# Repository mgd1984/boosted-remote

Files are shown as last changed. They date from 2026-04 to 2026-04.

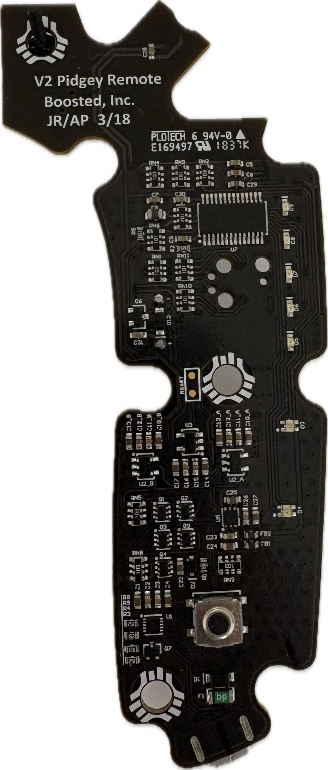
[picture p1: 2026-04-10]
mechanical/references/boosted_remote_pcb_front.png

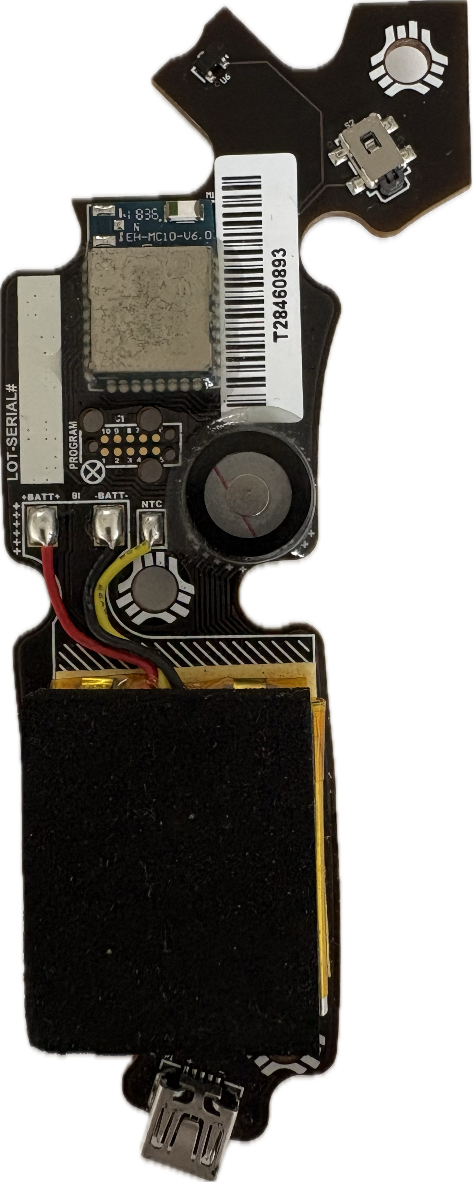
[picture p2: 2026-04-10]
mechanical/references/boosted_remote_pcb_back.png

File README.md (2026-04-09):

# Boosted Remote Reverse-Engineering Starter

This repo contains a first-pass reverse-engineered hardware recreation of the Boosted Boards thumbwheel remote:

- a Blender-generated enclosure
- a KiCad schematic
- a KiCad PCB
- documented assumptions tying the mechanical and electrical work back to source material

This is not a firmware-complete clone. The hardware is designed to match the known control architecture and packaging constraints while using currently accessible parts and a reproducible scripted workflow.

## Source Anchors

- Boosted USA product page for the later thumbwheel remote exterior reference:
  - <https://boostedusa.com/products/boosted-remote>
- Beam Break BLE reverse-engineering notes confirming later remote BLE behavior and pairing model:
  - <https://beambreak.org/articles/remote_ble_ids/>
- XR General Hospital replacement PCBA product confirming that a retrofit board in the original enclosure is practical:
  - <https://www.xrgeneralhospital.com/beta/p/remote-controller-pcba>

## Generated Assets

- Active enclosure blend: `outputs/blender/boosted_remote_enclosure.blend`
- Active PCB review blend: `outputs/blender/boosted_remote_pcb_all_layers.blend`
- Build123d CAD package: `mechanical/cad/`
- Build123d generator CLI: `mechanical/scripts/build_enclosure.py`
- Proxy-section extractor: `mechanical/scripts/analyze_proxy_glb.py`
- KiCad project: `electrical/kicad/boosted_remote.kicad_pro`
- Live board and schematic: `electrical/kicad/boosted_remote.kicad_pcb`, `electrical/kicad/boosted_remote.kicad_sch`
- Routing packet script: `electrical/scripts/route_packets.py`
- Netclass configurator: `electrical/scripts/configure_netclasses.py`
- Blender export path: `electrical/scripts/export_kicad_to_blender.py`
- Shared parameters: `config/remote_params.json`
- Reverse-engineering notes: `docs/reverse_engineering_notes.md`
- Build123d pipeline notes: `docs/build123d_enclosure.md`
- Repo navigation map: `docs/repo_map.md`

## Where To Work Now

- Mechanical source of truth: `mechanical/cad/`
- Generated Blender outputs: `outputs/blender/`
- Mechanical build entry point: `mechanical/scripts/build_enclosure.py`
- Shared parameter contract: `config/remote_params.json`
- Active KiCad project: `electrical/kicad/boosted_remote.kicad_pro`
- Active board and schematic: `electrical/kicad/boosted_remote.kicad_pcb`, `electrical/kicad/boosted_remote.kicad_sch`
- Electrical utilities and routing helpers: `electrical/scripts/`
- Mechanical utilities: `mechanical/scripts/`
- Historical electrical scripts: `history/electrical/scripts/`
- Historical mechanical scripts and studies: `history/mechanical/`
- Historical utilities: `history/utilities/`

## Repo Shape

- `electrical/kicad/`: live KiCad project only
- `electrical/scripts/`: active live-board utilities only
- `mechanical/cad/`: code-first enclosure source of truth
- `mechanical/scripts/`: active enclosure utilities only
- `mechanical/references/`: supporting 2D outline reference assets used by the CAD pipeline
- `outputs/`: generated Blender scenes, renders, and scratch outputs
- `history/electrical/`: older routing and migration helpers
- `history/mechanical/`: non-canonical lineage, experiments, displaced scenes, and older scripts
- `history/utilities/`: historical support scripts and geometry probes
- `config/`: shared project configuration and parameter contracts
- `docs/`: workflow notes plus `docs/repo_map.md` for a quick navigation guide

## Current Scope

- Boosted-style ergonomic shell with split enclosure
- thumbwheel opening and internal hall sensor location
- mini-USB charge-port cutout for external visual fidelity
- 1S LiPo power, charger, LDO, BLE MCU, LEDs, buzzer, deadman trigger, programming header
- first-pass PCB shaped to the enclosure cavity
- first-pass build123d enclosure generation for STEP/STL prototype outputs

## Verification Status

- Schematic ERC is down to warnings only on the generated custom-library setup.
- The promoted live PCB checkpoint is:
  - `electrical/kicad/boosted_remote.kicad_pcb`
  - 3 DRC warnings, all silkscreen-only
  - 25 unconnected items remaining
- The live board now includes validated packetized routing improvements over the original generator baseline.
  - Clean promoted packets so far: upper `SW1 -> U4` ground stitch and `PWR_BTN` escape/routing packet
- Experimental routing passes are only promoted when they reduce the open count without introducing blocker DRC categories.

## Known Gaps

- No firmware is included
- Dimensions are inferred and should be validated against a physical remote before fabrication
- The BLE protocol implementation required to pair with an original board is outside this repo
- The trigger and thumbwheel mechanism are mechanically approximated, not metrology-matched

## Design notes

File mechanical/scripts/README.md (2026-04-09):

# Mechanical Scripts

This folder keeps the active mechanical workflow entry points at the top level.

## Active Utilities

- `build_enclosure.py`
  - Main build123d enclosure generator.
- `analyze_proxy_glb.py`
  - Samples proxy cross-sections for enclosure fitting.

Older reconstruction and part-study scripts were moved to
`history/mechanical/scripts/`.

Use `mechanical/cad/` with the top-level scripts here for current enclosure
work.

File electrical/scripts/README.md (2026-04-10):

# Electrical Scripts

This folder keeps only the active live-board utilities at the top level.

Older one-off routing or migration helpers were moved to
`history/electrical/scripts/`.

## Primary Utilities

- `configure_netclasses.py`
  - Applies the project netclass layout.
- `export_jlc_bom.py`
  - Exports a JLCPCB-formatted BOM CSV filtered to the same placed parts as the CPL.
- `export_jlc_cpl.py`
  - Exports a JLCPCB-formatted CPL/pick-and-place CSV from the live KiCad board.
- `export_kicad_to_blender.py`
  - Regenerates PCB review assets for Blender.
- `import_kicad_blender_scene.py`
  - Blender-side importer used by the export script.
- `sync_board_outline.py`
  - Syncs the board outline from a chosen source contour layer. Defaults to the
    current `User.1` workflow.
- `update_pcb_outline_target.py`
  - Rebuilds `mechanical/references/boosted_remote_pcb_outline_target.svg`
    from the cleaned front/back PCB reference PNGs, mirroring the rear image and
    only blending it where the lower body is not occluded.

## Preferred Routing Flow

- `autoroute_iterate.py`
  - Primary routing automation path. Runs the KiCad DSN -> Freerouting -> SES
    -> DRC loop against a chosen board/report pair and only promotes an
    iteration when blocker-category counts do not regress and either opens or
    blocker counts improve. Use `--sync-outline-source pcb-svg` when the pass
    must route against `mechanical/references/boosted_remote_pcb_outline_target.svg`
    rather than whatever outline is already stored in the board file.

## Board Maintenance Utilities

- `sync_esp32_antenna_keepout.py`
  - Board-specific keepout normalization for the ESP32 module footprint.
- `sync_usb_footprint.py`
  - Board-specific re-sync of the generated local USB footprint onto the live
    board.

## Deterministic Manual Routing

- `manual_route_packets.py`
  - Deterministic packetized copper edits retained for explicit experiments and
    documented escape patterns. Prefer `autoroute_iterate.py` for normal routing
    passes.
- `rework_outline_candidate_nwx.py`
  - Candidate-board hotspot prep and deterministic reroute helper. Use
    `--ripup-only` when you want to clear edge-conflicting corridors before
    handing the board to `autoroute_iterate.py`.

## Baseline Generation

- `generate_kicad_remote.py`
  - Original project generator. Useful for reconstructing the baseline, but the
    live board is now manually maintained.
- `build_usb_mini_footprint.py`
  - Creates the local USB footprint variant used by the project.

Historical routing helpers now live under `history/electrical/scripts/`.

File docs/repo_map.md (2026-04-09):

# Repo Map

This repo is easier to navigate if you treat it as three layers: live sources,
active working files, and exploratory lineage.

## Live Sources

- `electrical/kicad/boosted_remote.kicad_pcb`
  - Current live board. This is the electrical source of truth.
- `electrical/kicad/boosted_remote.kicad_sch`
  - Current live schematic.
- `electrical/kicad/boosted_remote.kicad_pro`
  - Current KiCad project file.
- `electrical/kicad/boosted_remote.pretty/`
  - Custom footprint library used by the live board.
- `mechanical/cad/`
  - Current code-first enclosure model and validation logic.
- `mechanical/references/`
  - Supporting reference outlines consumed by the mechanical CAD package.
- `config/remote_params.json`
  - Shared geometry and packaging parameter contract.

## Active Working Areas

- `outputs/blender/boosted_remote_enclosure.blend`
  - Current enclosure output scene.
- `outputs/blender/boosted_remote_pcb_all_layers.blend`
  - Current PCB visualization / fit-check output scene.
- `mechanical/scripts/build_enclosure.py`
  - Main entry point for build123d enclosure generation.
- `electrical/scripts/export_kicad_to_blender.py`
  - Refresh the PCB review blend from the live KiCad board.
- `electrical/scripts/route_packets.py`
  - Main scripted routing helper for the live board.
- `electrical/scripts/configure_netclasses.py`
  - Applies netclass structure to the live project.
- `electrical/scripts/autoroute_iterate.py`
  - Specialized DSN -> Freerouting -> SES loop for automated routing passes.
- `mechanical/scripts/analyze_proxy_glb.py`
  - Samples proxy sections for the current enclosure workflow.

## Exploratory / Reference Areas

- `history/electrical/scripts/`
  - Older electrical routing and migration helpers retained for reference.
- `history/mechanical/`
  - Non-canonical geometry studies, displaced Blender scenes, and older mechanical scripts.
- `history/utilities/`
  - Historical support scripts and geometry probes.
- `outputs/renders/`
  - Output visuals, not a source directory.
- `outputs/tmp/`
  - Disposable generated intermediate data.

## Electrical Script Tiers

### Use most often

- `electrical/scripts/route_packets.py`
- `electrical/scripts/configure_netclasses.py`
- `electrical/scripts/export_kicad_to_blender.py`
- `electrical/scripts/sync_board_outline_from_user1.py`
- `electrical/scripts/sync_esp32_antenna_keepout.py`
- `electrical/scripts/sync_usb_footprint.py`

### Specialized live-board helpers

- `electrical/scripts/autoroute_iterate.py`
  - Use this when you want the DSN -> Freerouting -> SES iteration loop instead
    of manual packet routing.

### Baseline generators / setup

- `electrical/scripts/generate_kicad_remote.py`
- `electrical/scripts/build_usb_mini_footprint.py`

### Older packet experiments and migration helpers

- `history/electrical/scripts/manual_finish_route.py`
- `history/electrical/scripts/manual_route_signals.py`
- `history/electrical/scripts/rework_negative_bottom_cluster.py`
- `history/electrical/scripts/rework_to_two_layer.py`
- `history/electrical/scripts/rewrite_negative_bottom_cluster.py`

If a task touches the live board, start in `electrical/kicad/` and only reach for
the older helpers when a doc explicitly points to them.

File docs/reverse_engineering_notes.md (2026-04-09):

# Reverse-Engineering Notes

## What the sources support

The public source material is enough to establish the broad architecture of the later Boosted remote:

- The production remote uses a thumbwheel-driven control scheme and a compact hand-held enclosure.
- The community reverse-engineering work documents BLE-based communication and pairing behavior for the later remote family.
- Third-party replacement PCBAs exist that are intended to fit the original enclosure, which strongly suggests the packaging is simple enough to reproduce with a single custom board and a split shell.

## What is inferred here

The exact original board stack, component values, and enclosure dimensions are not fully public, so this repo makes explicit engineering assumptions:

- Enclosure style: Boosted-inspired later-generation remote, not the older trigger-only remote
- Exterior size: approximately 136 mm tall, 54 mm max width, 20 mm thick
- Shell construction: front and rear printed halves with screw bosses and a single internal PCB
- Battery: 1S LiPo in the 400 mAh to 600 mAh range
- Charging: mini-USB retained for exterior fidelity
- Logic/radio: ESP32-C3 module used as a practical BLE-capable stand-in
- Throttle sensing: linear hall sensor aligned to a thumbwheel magnet
- Safety input: rear deadman switch
- Indicators: five battery LEDs plus two status LEDs

## Why the hardware is modernized

Several original parts are either unknown, inconvenient to source, or tightly coupled to proprietary firmware. The design therefore substitutes accessible parts while preserving the same functional block diagram:

- `ESP32-C3-WROOM-02` replaces the unknown original radio/MCU
- `MCP73831-2-OT` provides simple 1S charging
- `TLV75533PDBV` provides clean 3.3 V regulation from the LiPo rail
- `DRV5055A3xDBZxQ1` provides a 3.3 V linear hall sensor suitable for wheel position sensing

## Mechanical intent

The enclosure is intentionally parametric and script-generated:

- the same parameter file drives the shell proportions and PCB cavity assumptions
- the thumbwheel pocket and hall sensor location are aligned by design
- the PCB outline is narrower than the outer shell so the printed enclosure can absorb final fit tweaks

## Internal layout target

An internal reference photo now anchors the first-order packaging assumptions:

- thumbwheel mechanism occupies the upper head volume, with the hall sensor placed just below and to the right of the wheel axis
- BLE/radio module sits in the upper-left third of the main PCB
- buzzer sits near the middle of the grip section
- LiPo pouch cell occupies most of the lower half of the enclosure
- mini-USB sits on the tail centerline

The current KiCad placement and Blender reference bodies are tuned toward that arrangement rather than a generic handheld remote.

## Validation standard for this pass

This first pass is considered successful if:

- the Blender enclosure opens cleanly and shows the intended shell split and cutouts
- the KiCad schematic opens without format errors
- the KiCad PCB opens, shows the expected footprint population, and passes a first DRC pass or at least reports a bounded set of remaining issues

Anything beyond that should be treated as prototype iteration work, not historical certainty.

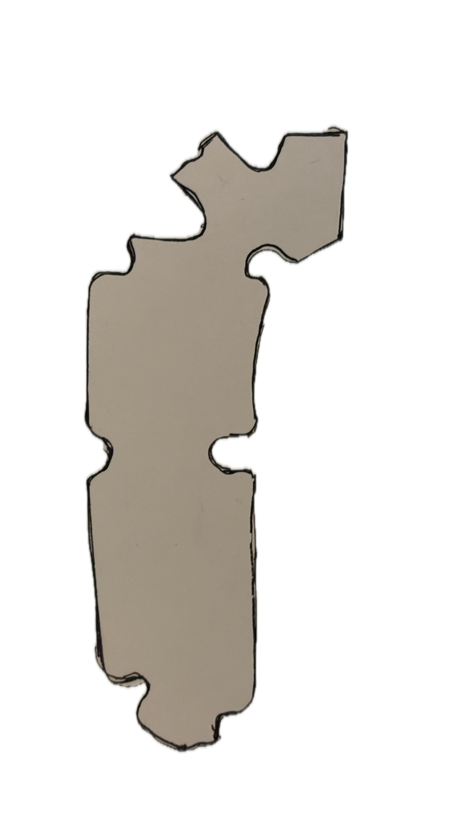
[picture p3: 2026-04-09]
mechanical/references/boosted_remote_pcb_outline_rough.png

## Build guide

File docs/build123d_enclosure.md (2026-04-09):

# Build123d Enclosure Pipeline

This repo now has a code-first mechanical path in addition to the existing Blender generator.

## Source Of Truth

- `config/remote_params.json` remains the primary parameter contract.
- `electrical/scripts/generate_kicad_remote.py` remains the fallback board-outline source when the live board does not already define `Edge.Cuts`.
- `mechanical/cad/` contains the build123d-driven enclosure model, validation, and export logic.

## What This Generates

- front shell
- rear shell
- full shell
- a simplified PCB/component envelope for visual clearance checks

## Quick Start

Install the CAD dependency:

```bash
python -m pip install -r requirements-mechanical.txt
```

Validate the current parameter set without generating solids:

```bash
python mechanical/scripts/build_enclosure.py --validate-only
```

Refresh the exterior profile stations from the proxy reconstruction GLB:

```bash
/Applications/Blender.app/Contents/MacOS/Blender --background --python mechanical/scripts/analyze_proxy_glb.py -- --repo-root "$PWD" --glb "$PWD/history/mechanical/proxy/TewTCTh6nBM-A_J6JKsw__trellis2_0d811f951772406a86d5d8f20232885d.glb" --out "$PWD/outputs/tmp/proxy_sections.json" --slice-step-mm 8.0
```

Generate the first-pass build123d enclosure outputs:

```bash
python mechanical/scripts/build_enclosure.py --formats step stl
```

Outputs are written to `outputs/build123d/` by default.

## Current Scope

This first pass is intentionally focused on:

- shell proportions and split-line
- proxy-driven exterior station fitting from the reconstructed GLB
- PCB cavity envelope
- thumbwheel, USB, LED, and button openings
- mounting bosses and counterbores
- parameter validation for early prototype iterations

It does not yet attempt a metrology-grade match to an original remote shell.

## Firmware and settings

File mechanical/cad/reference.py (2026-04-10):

from __future__ import annotations

import ast
import json
import re
import xml.etree.ElementTree as ET
from functools import lru_cache
from pathlib import Path

from .kicad_layout import load_live_board_layout
from .params import MechanicalParams


SHELL_SVG_OUTLINE_PATH = Path("mechanical/references/boosted_remote_outline_smooth_pixels.svg")
PCB_SVG_OUTLINE_PATH = Path("mechanical/references/boosted_remote_pcb_outline_target.svg")


@lru_cache(maxsize=4)
def board_outline_points(repo_root: Path) -> tuple[tuple[float, float], ...]:
    board_path = repo_root / "electrical" / "kicad" / "boosted_remote.kicad_pcb"
    board_text = board_path.read_text(encoding="utf-8")
    params_path = repo_root / "config" / "remote_params.json"
    mechanical = json.loads(params_path.read_text(encoding="utf-8"))["mechanical"]
    layout = load_live_board_layout(repo_root, mechanical)
    edge_points = _edge_cuts_outline_points(board_text, layout.offset_x_mm, layout.offset_y_mm)
    if edge_points is not None:
        return edge_points

    source_path = repo_root / "electrical" / "scripts" / "generate_kicad_remote.py"
    module = ast.parse(source_path.read_text(encoding="utf-8"), filename=str(source_path))
    for node in module.body:
        if isinstance(node, ast.FunctionDef) and node.name == "board_outline":
            for statement in node.body:
                if isinstance(statement, ast.Return):
                    points = ast.literal_eval(statement.value)
                    return tuple((float(x), float(y)) for x, y in points)
    raise RuntimeError("Unable to locate board_outline() in electrical/scripts/generate_kicad_remote.py")


def _edge_cuts_outline_points(board_text: str, offset_x_mm: float, offset_y_mm: float) -> tuple[tuple[float, float], ...] | None:
    blocks: list[str] = []
    current: list[str] = []
    depth = 0
    in_block = False
    for line in board_text.splitlines():
        stripped = line.lstrip()
        if not in_block and stripped.startswith("(gr_line"):
            in_block = True
            current = [line]
            depth = line.count("(") - line.count(")")
            if depth <= 0:
                block = "\n".join(current)
                if '(layer "Edge.Cuts")' in block:
                    blocks.append(block)
                in_block = False
            continue
        if in_block:
            current.append(line)
            depth += line.count("(") - line.count(")")
            if depth <= 0:
                block = "\n".join(current)
                if '(layer "Edge.Cuts")' in block:
                    blocks.append(block)
                in_block = False

    if not blocks:
        return None

    points: list[tuple[float, float]] = []
    for index, block in enumerate(blocks):
        start_match = re.search(r"\(start\s+([-0-9.]+)\s+([-0-9.]+)\)", block)
        end_match = re.search(r"\(end\s+([-0-9.]+)\s+([-0-9.]+)\)", block)
        if start_match is None or end_match is None:
            continue
        start = (float(start_match.group(1)) - offset_x_mm, float(start_match.group(2)) - offset_y_mm)
        end = (float(end_match.group(1)) - offset_x_mm, float(end_match.group(2)) - offset_y_mm)
        if index == 0:
            points.append(start)
        points.append(end)

    if len(points) < 4:
        return None
    if points[0] != points[-1]:
        points.append(points[0])
    return tuple(points)


@lru_cache(maxsize=8)
def user_layer_contour_points(repo_root: Path, layer_name: str = "User.1") -> tuple[tuple[float, float], ...]:
    params_path = repo_root / "config" / "remote_params.json"
    mechanical = json.loads(params_path.read_text(encoding="utf-8"))["mechanical"]
    layout = load_live_board_layout(repo_root, mechanical)
    board_path = repo_root / "electrical" / "kicad" / "boosted_remote.kicad_pcb"
    board_text = board_path.read_text(encoding="utf-8")

    block_lines: list[str] = []
    current: list[str] = []
    depth = 0
    in_block = False
    for line in board_text.splitlines():
        stripped = line.lstrip()
        if not in_block and stripped.startswith("(gr_poly"):
            in_block = True
            current = [line]
            depth = line.count("(") - line.count(")")
            if depth <= 0:
                candidate = "\n".join(current)
                if f'(layer "{layer_name}")' in candidate:
                    block_lines = current
                    break
                in_block = False
            continue

        if in_block:
            current.append(line)
            depth += line.count("(") - line.count(")")
            if depth <= 0:
                candidate = "\n".join(current)
                if f'(layer "{layer_name}")' in candidate:
                    block_lines = current
                    break
                in_block = False

    if not block_lines:
        raise RuntimeError(f"Unable to locate {layer_name} contour polygon in electrical/kicad/boosted_remote.kicad_pcb")

    points = [
        (float(x_mm) - layout.offset_x_mm, float(y_mm) - layout.offset_y_mm)
        for line in block_lines
        for x_mm, y_mm in re.findall(r"\(xy\s+([-0-9.]+)\s+([-0-9.]+)\)", line)
    ]
    if len(points) < 4:
        raise RuntimeError(f"{layer_name} contour polygon does not contain enough points")
    if points[0] != points[-1]:
        points.append(points[0])
    return tuple(points)


@lru_cache(maxsize=4)
def user1_contour_points(repo_root: Path) -> tuple[tuple[float, float], ...]:
    return user_layer_contour_points(repo_root, "User.1")


@lru_cache(maxsize=4)
def user1_shell_contour_points(repo_root: Path, pcb_shell_center_x_mm: float) -> tuple[tuple[float, float], ...]:
    return tuple((x_mm - pcb_shell_center_x_mm, -y_mm) for x_mm, y_mm in user1_contour_points(repo_root))


def _parse_svg_path_points(path_data: str) -> tuple[tuple[float, float], ...]:
    tokens = re.findall(r"[MLZ]|-?\d+(?:\.\d+)?", path_data)
    points: list[tuple[float, float]] = []
    index = 0
    command = None
    while index < len(tokens):
        token = tokens[index]
        if token in {"M", "L", "Z"}:
            command = token
            index += 1
            if command == "Z":
                break
            continue
        if command not in {"M", "L"}:
            raise RuntimeError("Unsupported SVG path command sequence in outline")
        if index + 1 >= len(tokens):
            raise RuntimeError("Malformed SVG path data in outline")
        x_mm = float(tokens[index])
        y_mm = float(tokens[index + 1])
        points.append((x_mm, y_mm))
        index += 2
    if len(points) < 4:
        raise RuntimeError("SVG outline path does not contain enough points")
    if points[0] != points[-1]:
        points.append(points[0])
    return tuple(points)
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

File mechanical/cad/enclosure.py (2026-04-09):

from __future__ import annotations

import importlib.util
import json
import sys
import types
from dataclasses import dataclass
from pathlib import Path

from .params import MechanicalParams, RemoteProjectData
from .reference import board_outline_points, horizontal_polygon_span, preferred_shell_contour_points, shell_xz_from_board


USB_PORT_CUT_CENTER_OFFSET_MM = 3.5


@dataclass(frozen=True)
class EnclosureArtifacts:
    outer_body: object
    full_shell: object
    front_shell: object
    rear_shell: object
    pcb_envelope: object


def _subtract_all(base_shape, cutters, part_factory=None):
    result = base_shape
    for cutter in cutters:
        result = result - cutter
        if part_factory is not None and hasattr(result, "wrapped"):
            result = part_factory(result.wrapped)
    return result


def _import_build123d():
    try:
        if importlib.util.find_spec("ezdxf.acc") is None:
            acc_module = types.ModuleType("ezdxf.acc")
            acc_module.USE_C_EXT = False
            sys.modules["ezdxf.acc"] = acc_module
        from ezdxf.entities.xdict import ExtensionDict
        from build123d import Box, Circle, Cylinder, Locations, Plane, Polyline, Pos, Rectangle, Rot, Sketch
        from build123d import CounterBoreHole, Hole, Mode, Part, extrude, fillet, loft, make_face, offset
        _ = ExtensionDict
        return {
            "Box": Box,
            "Circle": Circle,
            "CounterBoreHole": CounterBoreHole,
            "Cylinder": Cylinder,
            "Hole": Hole,
            "Locations": Locations,
            "Mode": Mode,
            "Part": Part,
            "Plane": Plane,
            "Polyline": Polyline,
            "Pos": Pos,
            "Rectangle": Rectangle,
            "Rot": Rot,
            "Sketch": Sketch,
            "extrude": extrude,
            "fillet": fillet,
            "loft": loft,
            "make_face": make_face,
            "offset": offset,
        }
    except ModuleNotFoundError as exc:
        raise ModuleNotFoundError(
            "build123d is required for enclosure generation. Install requirements-mechanical.txt first."
        ) from exc


def _rounded_profile(api, width_mm: float, thickness_mm: float, radius_mm: float):
    Rectangle = api["Rectangle"]
    fillet = api["fillet"]
    sketch = Rectangle(width_mm, thickness_mm)
    return fillet(sketch.vertices(), radius_mm)


def _default_profile_stations(mech: MechanicalParams) -> list[tuple[float, float, float, float, float]]:
    body_end = -mech.outer_height_mm
    return [
        (0.0, 0.0, mech.outer_width_top_mm * 0.76, mech.outer_thickness_mm * 0.74, 5.5),
        (-mech.top_bulb_height_mm * 0.42, 0.0, mech.outer_width_top_mm, mech.outer_thickness_mm, 8.0),
        (-mech.top_bulb_height_mm, 0.0, mech.outer_width_top_mm * 0.88, mech.outer_thickness_mm * 0.92, 7.0),
        (-(mech.top_bulb_height_mm + mech.grip_height_mm * 0.45), 0.0, mech.outer_width_grip_mm * 1.08, mech.outer_thickness_mm * 0.86, 6.2),
        (-(mech.top_bulb_height_mm + mech.grip_height_mm * 0.82), 0.0, mech.outer_width_grip_mm * 0.94, mech.outer_thickness_mm * 0.78, 5.2),
        (body_end + 12.0, 0.0, mech.outer_width_grip_mm * 0.72, mech.outer_thickness_mm * 0.58, 4.2),
        (body_end, 0.0, mech.outer_width_grip_mm * 0.52, mech.outer_thickness_mm * 0.42, 3.2),
    ]


def _proxy_sections_path(root: Path) -> Path:
    return root / "tmp" / "proxy_sections.json"


def _radius_for_station(width_mm: float, thickness_mm: float) -> float:
    return max(min(thickness_mm * 0.42, width_mm * 0.24, 8.5), 1.8)


def _proxy_profile_stations(project: RemoteProjectData) -> list[tuple[float, float, float, float, float]] | None:
    path = _proxy_sections_path(project.root)
    if not path.exists():
        return None
    payload = json.loads(path.read_text(encoding="utf-8"))
    stations = []
    for entry in payload.get("stations", []):
        width_mm = float(entry["width_mm"])
        thickness_mm = float(entry["thickness_mm"])
        z_from_top_mm = float(entry["z_from_top_mm"])
        if width_mm < 8.0 or thickness_mm < 4.0:
            continue
        stations.append(
            (
                -z_from_top_mm,
                0.0,
                width_mm,
                thickness_mm,
                _radius_for_station(width_mm, thickness_mm),
            )
        )

    if len(stations) < 5:
        return None

    # Add small cap stations so the loft closes more naturally at the nose and tail.
    first_z, _, first_width, first_thickness, _ = stations[0]
    last_z, _, last_width, last_thickness, _ = stations[-1]
    nose_station = (first_z + 6.0, 0.0, max(first_width * 0.88, 18.0), max(first_thickness * 0.55, 6.0), _radius_for_station(max(first_width * 0.88, 18.0), max(first_thickness * 0.55, 6.0)))
    tail_station = (-project.mechanical.outer_height_mm, 0.0, max(last_width * 0.45, 10.0), max(last_thickness * 0.45, 4.0), _radius_for_station(max(last_width * 0.45, 10.0), max(last_thickness * 0.45, 4.0)))
    return [nose_station, *stations, tail_station]


def _apply_user1_contour_to_stations(project: RemoteProjectData, stations: list[tuple[float, float, float, float, float]]) -> list[tuple[float, float, float, float, float]]:
    contour = preferred_shell_contour_points(project.root, project.mechanical)
    shaped: list[tuple[float, float, float, float, float]] = []
    for z_mm, x_center_mm, width_mm, thickness_mm, radius_mm in stations:
        span = horizontal_polygon_span(z_mm, contour)
        if span is None:
            shaped.append((z_mm, x_center_mm, width_mm, thickness_mm, radius_mm))
            continue
        min_x_mm, max_x_mm = span
        contour_width_mm = max_x_mm - min_x_mm
        contour_center_mm = (min_x_mm + max_x_mm) * 0.5
        shaped.append(
            (
                z_mm,
                contour_center_mm,
                max(contour_width_mm + 1.2, width_mm),
                thickness_mm,
                _radius_for_station(max(contour_width_mm, width_mm), thickness_mm),
            )
        )
    return shaped


def _profile_stations(project: RemoteProjectData) -> list[tuple[float, float, float, float, float]]:
    proxy = _proxy_profile_stations(project)
    base = proxy if proxy is not None else _default_profile_stations(project.mechanical)
    return _apply_user1_contour_to_stations(project, base)


def _build_lofted_body(api, stations: list[tuple[float, float, float, float, float]]):
    Plane = api["Plane"]
    Pos = api["Pos"]
    Sketch = api["Sketch"]
    loft = api["loft"]

    profiles = Sketch() + [
        Plane.XY.offset(z_mm) * Pos(x_center_mm, 0, 0) * _rounded_profile(api, width_mm, thickness_mm, radius_mm)
        for z_mm, x_center_mm, width_mm, thickness_mm, radius_mm in stations
    ]
    return loft(profiles)
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

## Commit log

2026-04-09 Initial repo import
    [boosted_remote.kicad_pcb, boosted_remote.kicad_sch]
2026-04-09 Remove legacy root board file
    [boosted_remote.kicad_pcb]
